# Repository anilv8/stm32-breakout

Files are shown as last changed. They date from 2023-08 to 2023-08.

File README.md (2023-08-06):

# stm32-breakout
# Schematic of circuit
schematic

## ERC Result
erc

# PCB Board
### Front Copper
front-copper

### Back copper
back-copper

## DRC Result
![Uploading drc.png…]()

## 3D view of PCB
### Front:
3d-view-front

### Back:
3d-view-back

## Gerber
### Front Copper
gerber-front-copper

### Back Copper
gerber-back-copper

# BOM
| Item	| Qty	| Reference(s)	| Value	| LibPart	| Footprint	| Datasheet |
| ----- | ----- | ----- | ----- | ----- | ----- | ----- |
| 1	| 2	| C1, C2 |	1u	| Device:C |	Capacitor_SMD:C_0603_1608Metric |	~ |
| 2	| 1	| C3 |	4u7	| Device:C	| Capacitor_SMD:C_0603_1608Metric |	~ |
| 3 |	5 |	C4, C5, C6, C7, C9 |	100n |	Device:C	| Capacitor_SMD:C_0402_1005Metric |	~ |
| 4 |	1 |	C8 |	1u |	Device:C |	Capacitor_SMD:C_0402_1005Metric	| ~ |
| 5	| 2	| C10, C11	| 30p	| Device:C	| Capacitor_SMD:C_0402_1005Metric	| ~ |
| 6 |	1 |	D1	| GREEN |	Device:LED_Small |	LED_SMD:LED_0603_1608Metric |	~ |
| 7	| 1	| D2 |	BLUE	| Device:LED_Small	| LED_SMD:LED_0603_1608Metric |	~ |
| 8 |	1	| FB1	| 100R	| Device:FerriteBead	| Inductor_SMD:L_0805_2012Metric |	~ |
| 9 |	4	| H1, H2, H3, H4 |	MountingHole |	Mechanical:MountingHole	MountingHole:MountingHole_2.2mm_M2 |	~ |
| 10 | 1 |	J1 |	USB_B_Micro	| Connector:USB_B_Micro |	Connector_USB:USB_Micro-B_Wuerth_629105150521	| ~ |
| 11	| 2	| J2, J3 |	Conn_01x15	| Connector_Generic:Conn_01x15	| Connector_PinHeader_2.54mm:PinHeader_1x15_P2.54mm_Vertical	| ~ |
| 12 |	1	| JP1	| SolderJumper_2_Open |	Jumper:SolderJumper_2_Open	| Jumper:SolderJumper-2_P1.3mm_Open_Pad1.0x1.5mm |	~ |
| 13	| 1	| L1	| 27n |	Device:L	| Inductor_SMD:L_0402_1005Metric | ~ |
| 14 |	2 |	R1, R3	| 1k5 |	Device:R |	Resistor_SMD:R_0603_1608Metric	| ~ |
| 15	| 1	| R2	| 10k	| Device:R	| Resistor_SMD:R_0402_1005Metric	| ~ |
| 16 |	1 |	R4	| 1k5	| Device:R |	Resistor_SMD:R_0402_1005Metric |	~ |
| 17 | 1	| U1	| XC6206P333MR	| Regulator_Linear:XC6206PxxxMR	| Package_TO_SOT_SMD:SOT-23-3	| https://www.torexsemi.com/file/xc6206/XC6206.pdf |
| 18	| 1 | U2	| STM32F103C8Tx	| MCU_ST_STM32F1:STM32F103C8Tx	| Package_QFP:LQFP-48_7x7mm_P0.5mm |	https://www.st.com/resource/en/datasheet/stm32f103c8.pdf |
| 19 |	1|	Y1 |	8MHz	| Device:Crystal_Small	| Crystal:Crystal_SMD_5032-2Pin_5.0x3.2mm	| ~ |

# REFERENCES
[1]  https://www.youtube.com/watch?v=wLwKgMBWhpY

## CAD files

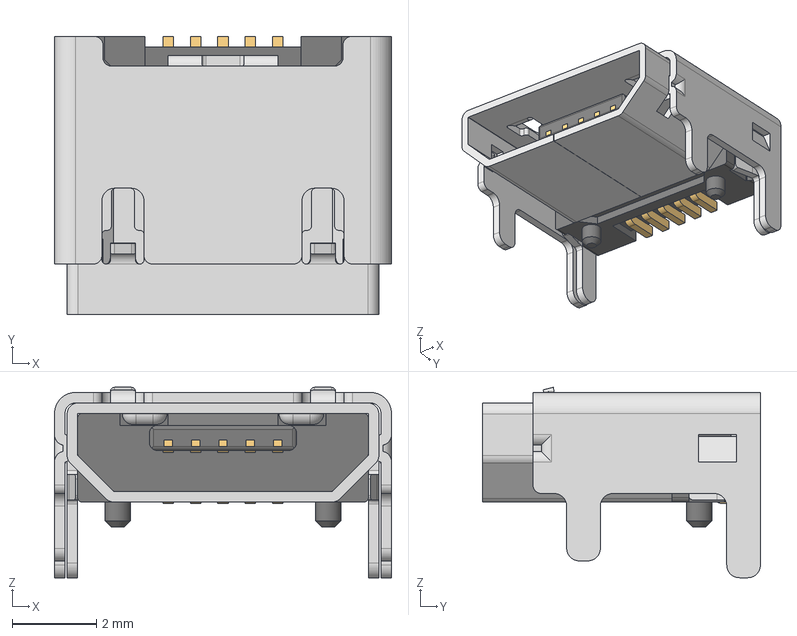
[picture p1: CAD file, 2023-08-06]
629105150521 (rev1).stp
8.00 x 6.60 x 4.52 mm
629105150521_Housing
629105150521_Pin1 x 4
629105150521_Pin2
629105150521_Shielding2
629105150521_Shielding

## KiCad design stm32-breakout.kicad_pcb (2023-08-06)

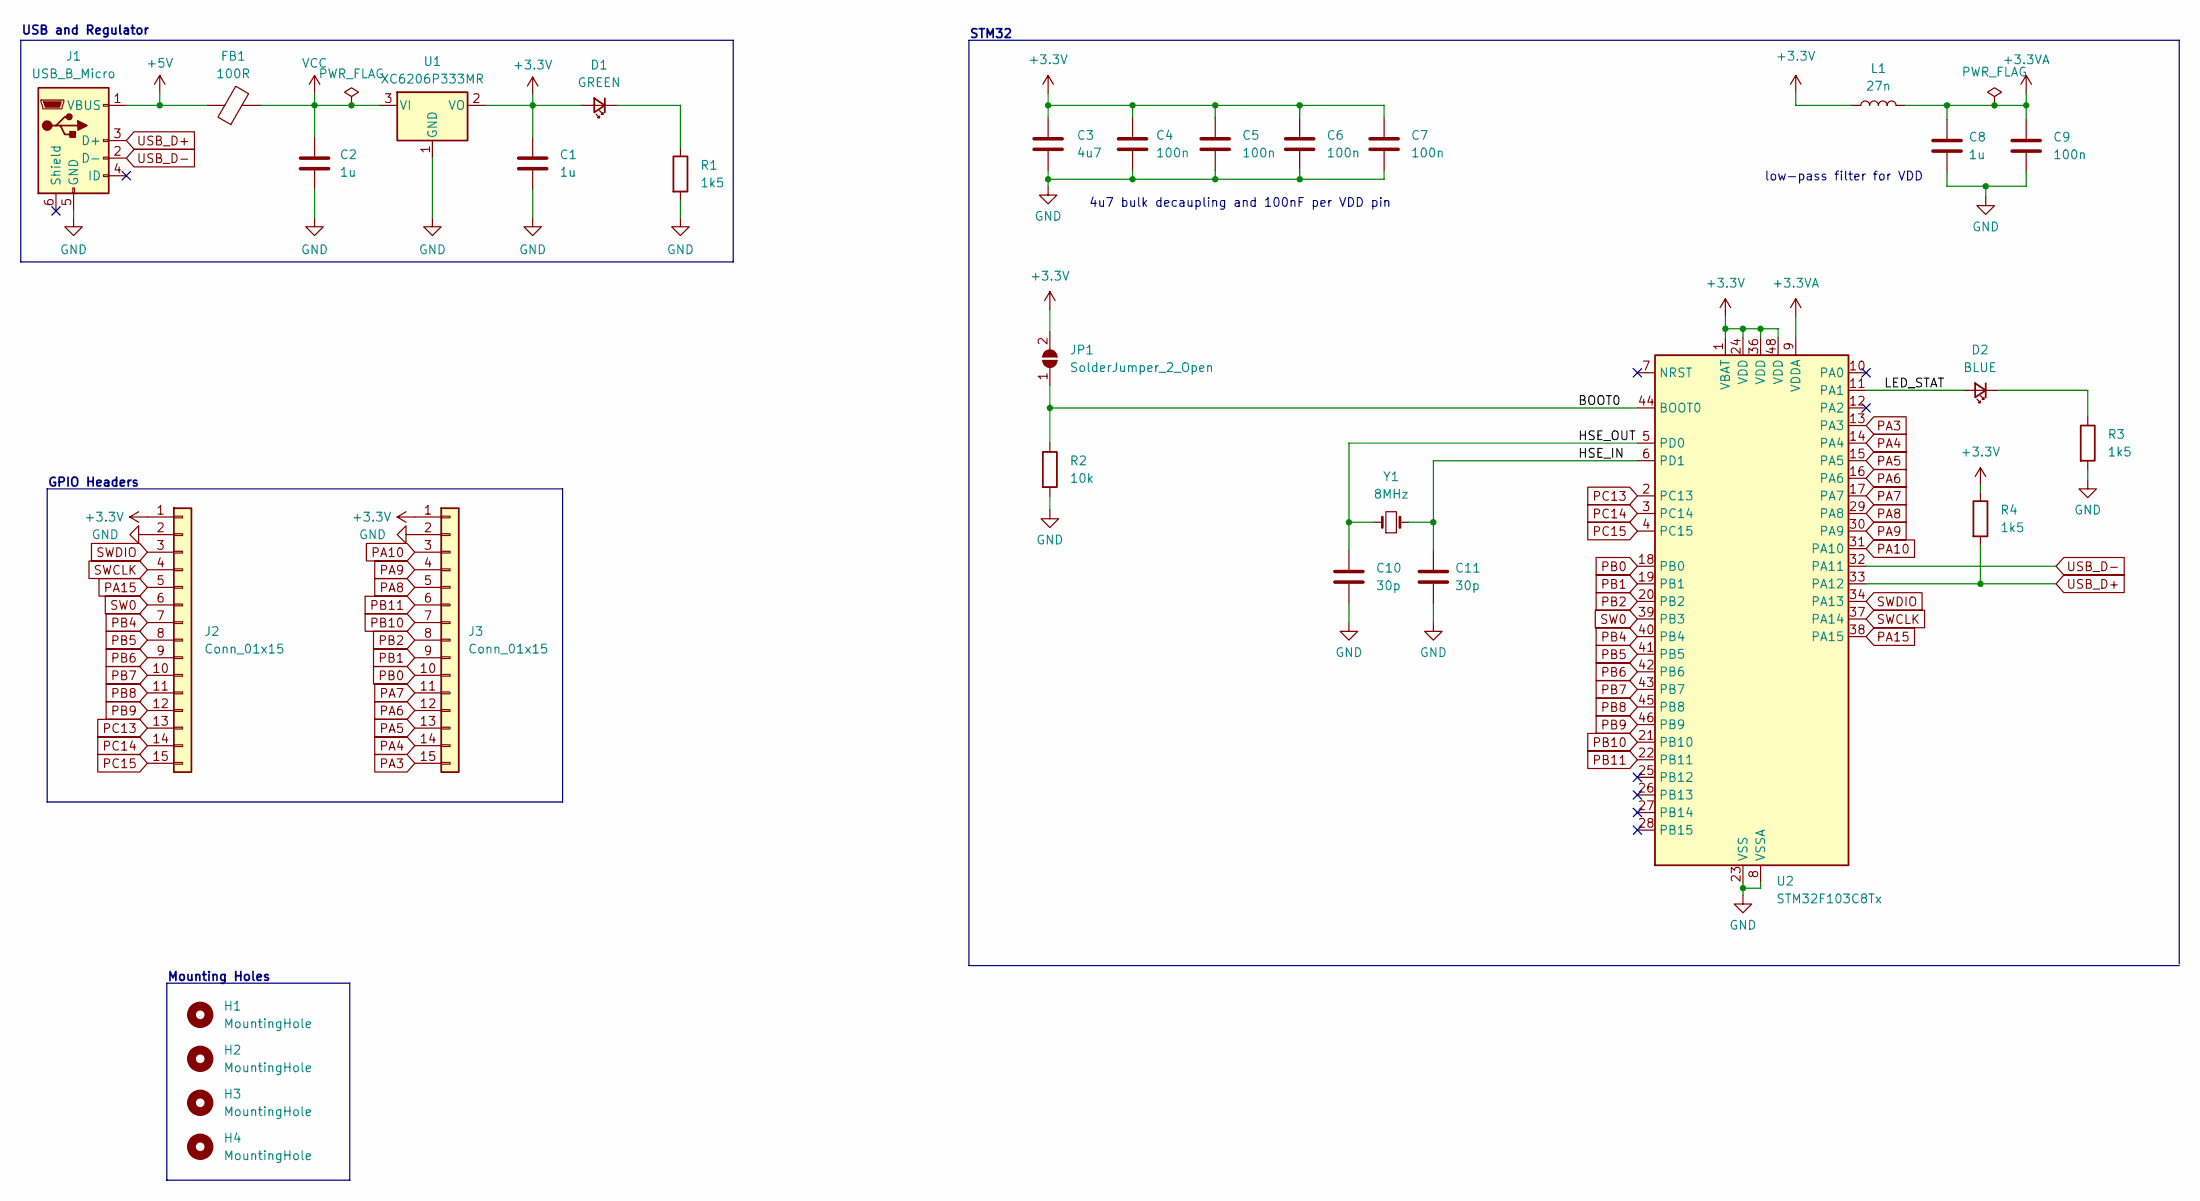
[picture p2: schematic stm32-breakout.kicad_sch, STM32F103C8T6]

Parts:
C1, C2: 1u; C_0603_1608Metric
C3: 4u7; C_0603_1608Metric
C4, C5, C6, C7, C9: 100n; C_0402_1005Metric
C8: 1u; C_0402_1005Metric
C10, C11: 30p; C_0402_1005Metric
D1: GREEN; LED_0603_1608Metric
D2: BLUE; LED_0603_1608Metric
FB1: 100R; L_0805_2012Metric
H1, H2, H3, H4: MountingHole; MountingHole_2.2mm_M2
J1: USB_B_Micro; USB_Micro-B_Wuerth_629105150521
J2, J3: Conn_01x15; PinHeader_1x15_P2.54mm_Vertical
JP1: SolderJumper_2_Open; SolderJumper-2_P1.3mm_Open_Pad1.0x1.5mm
L1: 27n; L_0402_1005Metric
R1, R3: 1k5; R_0603_1608Metric
R2: 10k; R_0402_1005Metric
R4: 1k5; R_0402_1005Metric
U1: XC6206P333MR; SOT-23-3
U2: STM32F103C8Tx; LQFP-48_7x7mm_P0.5mm
Y1: 8MHz; Crystal_SMD_5032-2Pin_5.0x3.2mm

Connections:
+3.3V: C1.1, C3.1, C4.1, C5.1, C6.1, C7.1, D1.2 (A), J2.1, J3.1, JP1.2 (B), L1.1, R4.1, U1.2 (VO), U2.1 (VBAT), U2.24 (VDD), U2.36 (VDD), U2.48 (VDD)
+3.3VA: C8.1, C9.1, L1.2, U2.9 (VDDA)
+5V: FB1.1, J1.1 (VBUS)
/BOOT0: JP1.1 (A), R2.1, U2.44 (BOOT0)
/HSE_IN: C11.1, U2.6 (PD1), Y1.2
/HSE_OUT: C10.1, U2.5 (PD0), Y1.1
/LED_STAT: D2.2 (A), U2.11 (PA1)
GND: C1.2, C2.2, C3.2, C4.2, C5.2, C6.2, C7.2, C8.2, C9.2, C10.2, C11.2, J1.5 (GND), J2.2, J3.2, R1.2, R2.2, R3.2, U1.1 (GND), U2.8 (VSSA), U2.23 (VSS), U2.35 (VSS), U2.47 (VSS)
unnamed: D1.1 (K), R1.1
unnamed: D2.1 (K), R3.1
PA3: J3.15, U2.13 (PA3)
PA4: J3.14, U2.14 (PA4)
PA5: J3.13, U2.15 (PA5)
PA6: J3.12, U2.16 (PA6)
PA7: J3.11, U2.17 (PA7)
PA8: J3.5, U2.29 (PA8)
PA9: J3.4, U2.30 (PA9)
PA10: J3.3, U2.31 (PA10)
PA15: J2.5, U2.38 (PA15)
PB0: J3.10, U2.18 (PB0)
PB1: J3.9, U2.19 (PB1)
PB2: J3.8, U2.20 (PB2)
PB4: J2.7, U2.40 (PB4)
PB5: J2.8, U2.41 (PB5)
PB6: J2.9, U2.42 (PB6)
PB7: J2.10, U2.43 (PB7)
PB8: J2.11, U2.45 (PB8)
PB9: J2.12, U2.46 (PB9)
PB10: J3.7, U2.21 (PB10)
PB11: J3.6, U2.22 (PB11)
PC13: J2.13, U2.2 (PC13)
PC14: J2.14, U2.3 (PC14)
PC15: J2.15, U2.4 (PC15)
SW0: J2.6, U2.39 (PB3)
SWCLK: J2.4, U2.37 (PA14)
SWDIO: J2.3, U2.34 (PA13)
USB_D+: J1.3 (D+), R4.2, U2.33 (PA12)
USB_D-: J1.2 (D-), U2.32 (PA11)
VCC: C2.1, FB1.2, U1.3 (VI)

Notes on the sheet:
Mounting Holes
STM32
USB and Regulator
GPIO Headers
low-pass filter for VDD
4u7 bulk decaupling and 100nF per VDD pin

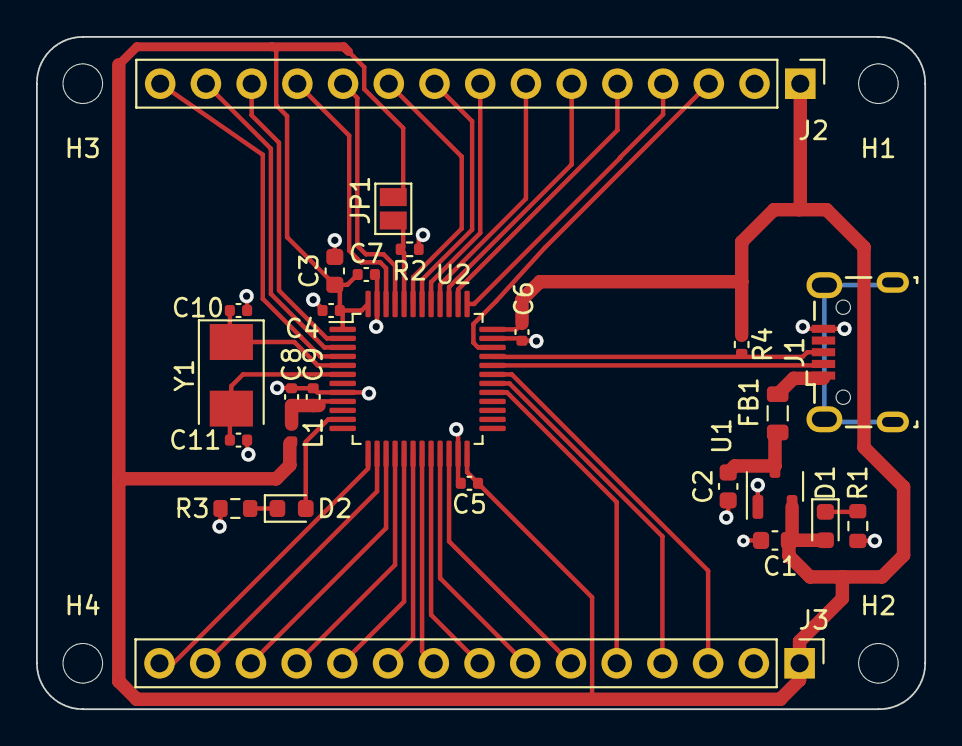
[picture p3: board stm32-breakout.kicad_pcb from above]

Board: 2 copper layers, 49.3 x 37.3 mm, 30 parts (0 on the bottom side), 39 nets.
